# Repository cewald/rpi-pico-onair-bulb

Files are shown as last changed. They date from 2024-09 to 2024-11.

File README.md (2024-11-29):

# DIY On-Air-Display controlled by a REST-API

This is the repository for a DIY on-air-display using a [MAX7219 8x32 LED matrix](https://www.amazon.de/Youmile-Control-LED-Anzeigemodul-Arduino-Raspberry/dp/B099F2MN15) controlled by a [Raspberry Pico W](https://www.raspberrypi.com/products/raspberry-pi-pico/) running a [micropython](https://micropython.org/) REST-API using [Microdot](https://microdot.readthedocs.io/en/latest/).

Gif animation of the connected display DIY On-Air-Display in action

## Setup

### Parts

* [MAX7219 8x32 LED matrix](https://www.amazon.de/Youmile-Control-LED-Anzeigemodul-Arduino-Raspberry/dp/B099F2MN15)
* [Raspberry Pico W](https://www.raspberrypi.com/products/raspberry-pi-pico/)
* [Push-Button](https://www.amazon.de/dp/B081TV622R?smid=AT0FJ7CZCB0G9)
* 5V Micro-USB power-source or USB cable
* Wires
* [Casing](#casing)

### Wiring

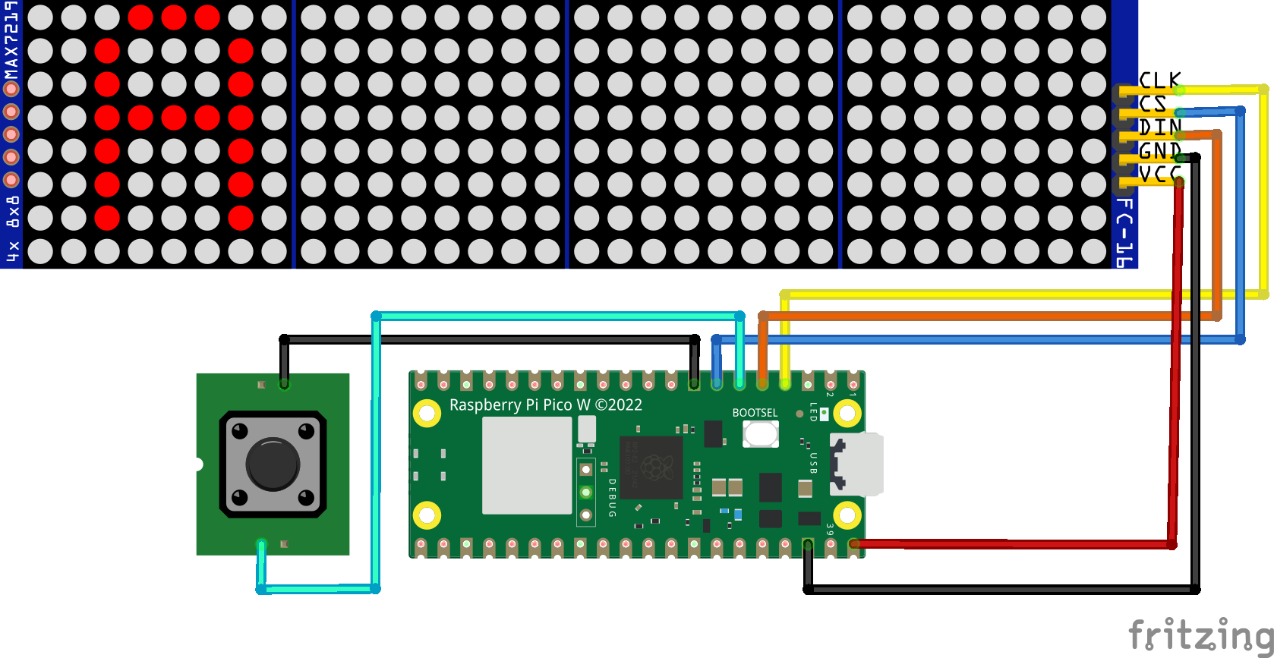
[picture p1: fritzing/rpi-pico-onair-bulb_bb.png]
wirechart


### Casing

I created a [simple 3d printed case](https://cad.onshape.com/documents/71781608140f03a0c4abf547/w/2687a64c73f126bf467bbb62/e/b8791e3240e13732a7194e4d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) using [OnShape](https://www.onshape.com) you can use and change to your desired needs. By default it fits the display, RPi and the button meantioned above and you can mount it to the wall. I used a [3mm translucent white acrylic glas](https://www.amazon.de/dp/B09J3SW25R) to cover the front, but this is oc optional and has only an aesthetic purpose.

## Configuration

Make a copy of `config.sample.json`, name it `config.json` and apply your configs, like your WiFi credentials etc. .

Flash your Raspberry Pi Zero W with the [latest Micropython](https://micropython.org/download/RPI_PICO_W/) version (instructions on page).

Upload all files to the root folder of the Raspberry Pi Zero W.

After that you can unmount your Pi and plug it into a suitable power-source. The device should power-up instantly and show its state on the display until it is connected.

When it is connected the display initially shows the given IP address. But you should also be able to use the hostname set in the configs (default: `http://on-air-bulb`).

Now the device is running and accessible via it's [API](#api-docs) and the button.

## API Docs

<details>
   <summary>
      <code>GET</code> <code>/on</code> Turn the default image on
   </summary>

   #### Parameters
   > None

   #### Responses
   > | http-code | content-type | response |
   > | --------- | ------------ | -------- |
   > | `200` | `application/json; charset=UTF-8` | JSON |

   ##### Example cURL
   > ```bash
   >  curl -X GET http://192.168.0.111/on
   > ```
</details>

<details>
   <summary>
      <code>GET</code> <code>/on/:text</code> Turn any text value on
   </summary>

   #### Parameters
   > | name | type | data-type | description |
   > | ---- | ---- | --------- | ----------- |
   > | `text` | required | string (url-encoded) | the text-string you want to display, if it is longer than 4 letters it will scroll back and forth |

   #### Responses
   > | http-code | content-type | response |
   > | --------- | ------------ | -------- |
   > | `200` | `application/json; charset=UTF-8` | `{"success": true, "state": 1}` |

   ##### Example cURL
   > ```bash
   >  curl -X GET http://192.168.0.111/on/Hello%20World
   > ```
</details>

<details>
   <summary>
      <code>GET</code> <code>/off</code> Turn the display off
   </summary>

   #### Parameters
   > None

   #### Responses
   > | http-code | content-type | response |
   > | --------- | ------------ | -------- |
   > | `200` | `application/json; charset=UTF-8` | `{"success": true, "state": 0}` |

   ##### Example cURL
   > ```bash
   >  curl -X GET http://192.168.0.111/off
   > ```
</details>

<details>
   <summary>
      <code>GET</code> <code>/toggle</code> Toggle the default image
   </summary>

   #### Parameters
   > None

   #### Responses
   > | http-code | content-type | response |
   > | --------- | ------------ | -------- |
   > | `200` | `application/json; charset=UTF-8` | `{"success": true, "state": 1}` |

   ##### Example cURL
   > ```bash
   >  curl -X GET http://192.168.0.111/toggle
   > ```
</details>

<details>
   <summary>
      <code>GET</code> <code>/toggle/:text</code> Toggle any text value
   </summary>

   #### Parameters
   > | name | type | data-type | description |
   > | ---- | ---- | --------- | ----------- |
   > | `text` | required | string (url-encoded) | the text-string you want to display, if it is longer than 4 letters it will scroll back and forth |

   #### Responses
   > | http-code | content-type | response |
   > | --------- | ------------ | -------- |
   > | `200` | `application/json; charset=UTF-8` | `{"success": true, "state": 1}` |

   ##### Example cURL
   > ```bash
   >  curl -X GET http://192.168.0.111/toggle/hallo%20welt
   > ```
</details>

<details>
   <summary>
      <code>GET</code> <code>/brightness/:value</code> Set the brightness of the display
   </summary>

   #### Parameters
   > | name | type | data-type | description |
   > | ---- | ---- | --------- | ----------- |
   > | `brightness` | required | int | set it to a value between `1` and `15`, default: `1` |

   #### Responses
   > | http-code | content-type | response |
   > | --------- | ------------ | -------- |
   > | `200` | `application/json; charset=UTF-8` | JSON |

   ##### Example cURL
   > ```bash
   >  curl -X GET http://192.168.0.111/brightness/5
   > ```
</details>

<details>
   <summary>
      <code>GET</code> <code>/brightness</code> Reset the brightness value
   </summary>

   #### Parameters
   > None

   #### Responses
   > | http-code | content-type | response |
   > | --------- | ------------ | -------- |
   > | `200` | `application/json; charset=UTF-8` | `{"success": true, "state": 1}` |

   ##### Example cURL
   > ```bash
   >  curl -X GET http://192.168.0.111/brightness
   > ```
</details>

## Apple Shortcut

I made [*this small shortcut*](https://www.icloud.com/shortcuts/6cb9b6efc35a46379dafb8790af98a7c) using the [Shortcut feature of MacOS and iOS](https://support.apple.com/guide/shortcuts/welcome/ios) – this way you can easily call it from any widget and/or from your home-screen. You can change the target URL if needed, by default it is the hostname set in the `configs.json` (Default: `on-air-bulb`).

## Create a custom image (transform image into `byte_array`)

By default the `byte_array` representations of the `image-0.png` and `image-1.png` in the root folder in `src/image.py` is displayed after another in an short interval (blinking animation).

To create a custom images follow these steps:

1. install `pillow` library (image-library):
   ```bash
   pip3 install pillow
   ```
1. create your monochrome (black and white, with a background) PNG images in the dimensions of 8x32px and replace the `image-0.png` and `image-1.png` in the root folder
1. run the `image2bytearray` script in the `/scripts` folder:
   ```bash
   python3 scripts/image2bytearray.py
   ```
1. the `src/image.py` should now be updated with the `byte_array` representation of your image

---

## License

This project is licensed under the [GNU General Public License v3.0](LICENSE).

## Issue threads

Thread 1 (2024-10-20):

Handle WiFi reconnect using for the API

cewald, 2024-10-20:
Currently the RPi isn't reconnecting after the connection is interupted.
Maybe we should also show an error msg on the display during dis- and reconnection.

cewald, 2024-11-14:
Solved by 9c17780c648660aae0d647ee62a6a88004ebafa4

Closed 2024-11-14.

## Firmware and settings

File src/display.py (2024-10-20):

from asyncio import create_task, sleep
from machine import Pin, SPI
from lib.max7219 import Matrix8x8
from lib.url_decode import url_decode
from src.image import image_one, image_zero


class Display(object):
    def __init__(self):
        print("Init display")

        self.text = ""
        self.default_brightness = 1
        self.current_brightness = self.default_brightness

        self.matrix_count = 4
        self.spi = SPI(0, sck=Pin(2), mosi=Pin(3))
        self.cs = Pin(5, Pin.OUT)
        self.display = Matrix8x8(self.spi, self.cs, self.matrix_count)

        self.bounce_task = None
        self.blink_task = None

        self.display.brightness(0)
        self.display.fill(0)
        self.display.show()
        self.display.brightness(self.default_brightness)

    def stop_async_tasks(self):
        if self.bounce_task and not self.bounce_task.done():
            self.bounce_task.cancel()

        if self.blink_task and not self.blink_task.done():
            self.blink_task.cancel()

        self.blink_task = None
        self.bounce_task = None

    def show_text(self, text="PICO", delay=0.1):
        text = url_decode(text)

        if self.text == text:
            return

        self.clear()
        self.text = text

        if len(text) > 4:
            self.bounce_task = create_task(self.bounce_text(text=text, delay=delay))
        else:
            self.display.text(text, 0, 0, 1)
            self.display.show()

    async def bounce_text(self, text, delay=0.1, end_wait=0.5):
        length = len(text) * 8
        max_offset = length - 32
        direction = 1
        pos = 0

        switch = False
        is_initialized = False

        while True:
            self.display.fill(0)
            self.display.text(text, -pos, 0, 1)
            self.display.show()

            await sleep(delay)

            if switch or not is_initialized:
                await sleep(end_wait)
                switch = False
                is_initialized = True

            pos += direction

            if pos >= max_offset or pos <= 0:
                direction *= -1
                switch = True

    def draw_image(self, image_byte_array=bytearray([])):
        for y in range(8):
            for x in range(self.matrix_count * 8):
                byte_index = (y * self.matrix_count) + (x // 8)
                byte = image_byte_array[byte_index]
                bit = (byte >> (7 - (x % 8))) & 1
                self.display.pixel(x, y, bit)

        self.display.show()

    def show_image(self, blink=True):
        global image_zero
        global image_one

        self.clear()

        if not blink:
            self.draw_image(image_zero)
            return

        self.blink_task = create_task(self.blink_image())

    async def blink_image(self):
        while True:
            self.draw_image(image_zero)
            await sleep(0.5)
            self.draw_image(image_one)
            await sleep(0.5)

    def clear(self):
        self.text = ""
        self.stop_async_tasks()

        self.display.fill(0)
        self.display.show()

    def brightness(self, value: int = None):
        if not value or not 0 <= value <= 15:
            self.current_brightness = self.default_brightness
        else:
            self.current_brightness = value

        self.display.brightness(self.current_brightness)

        return self.current_brightness


display = Display()

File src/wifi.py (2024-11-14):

import network
from asyncio import sleep
from src.config import get_config
from src.display import display

config = get_config()
wlan = network.WLAN(network.STA_IF)


async def show_text(text, showFor: float):
    display.show_text(text=text)
    await sleep(showFor)


async def connect_to_wifi(ssid=config["wifiName"], password=config["wifiPassword"]):
    wlan.active(True)

    network.hostname(config["hostname"])
    wlan.connect(ssid, password)

    max_wait = 20

    print("Connecting to WiFi")
    await show_text(text="wlcm", showFor=1)

    count = 0
    while not wlan.isconnected() and max_wait > 0:
        print(".", end="")

        count = count + 1 if count < 4 else 1
        text = ""
        for i in range(count):
            text = text + "."

        await show_text(text=text, showFor=1)
        max_wait -= 1

    if max_wait == 0:
        print("\nFailed to connect")
        display.show_text("fail")
        return

    print("\nConnected to WiFi:", wlan.ifconfig()[0])
    print("Hostname:", network.hostname())

    await show_text(text="cnct", showFor=0.8)
    await show_text(text="IP:" + wlan.ifconfig()[0], showFor=20)
    display.clear()


async def maintain_wifi():
    print("Add Wifi maintenance")
    if not wlan.isconnected():
        print("WiFi disconnected, attempting to reconnect...")
        wlan.disconnect()
        connect_to_wifi()


def get_wifi():
    return wlan.ifconfig()

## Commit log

2024-09-21 feat: connect to wifi and turn on led
2024-09-21 feat: improve print
2024-09-22 fix: refactor some code
    [display.py, server.py, wifi.py]
2024-09-22 fix: don't show start-up-message
    [display.py]
2024-09-22 feat: prepare button
2024-09-22 feat: run server and button async
2024-09-25 fix: make button non-blocking for asyncio
2024-09-25 fix: show connect on display
    [wifi.py]
2024-09-25 fix: redirect if empty param
    [server.py]
2024-09-25 fix: handle text change
    [display.py, server.py]
2024-09-25 fix: make async scroller really work
    [display.py, server.py]
2024-09-26 fix: add button and put to real use
    [display.py, server.py]
2024-09-27 fix: change GPIO pin for button
2024-09-27 fix: use asyncio sleep for button
2024-09-28 feat: add fritzing-files
    [rpi-pico-onair-bulb.fzz]
2024-10-20 chore: add the case to README.md
2024-10-20 fix: toggle text also by url-encoded string
    [server.py]
2024-10-20 fix: set default value for brightness method of display class
    [display.py]
2024-11-14 fix(1): reconnect wifi after disconnect (#1)
    [wifi.py]
